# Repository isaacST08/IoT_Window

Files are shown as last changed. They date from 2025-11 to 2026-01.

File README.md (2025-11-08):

# IoT Window Project

This is a project creating an IoT (Internet of Things) window controller.

The project uses a Raspberry Pi Pico for the controller, a stepper motor, a
TMC2209 stepper motor driver, and a acme threaded rod for the physical movement
of the window, and 3D printed parts for mounting.

This device is designed to be used with Home assistant. On boot up of the
device, the device will send a HA device discovery packet that will
automatically configure the device in Home Assistant (when home assistant has
the MQTT integration set up to point to the same server you set up the IoT
window to connect to).

# Setup

Not included in the repo is the required `secrets.h` file that resides in the
`src` directory. To generate this file, use the command:

```
make secrets.h
```

If the file already exists, then nothing will happen, if it doesn't, then the
file will be created with all the required variables pre-filled with placeholder
values. Replace these values with the correct values for your network SSID and
password, as well as information for connecting to your MQTT server.

For manual creation of the `secrets.h` file, use the following template:

The file named `secrets.h` must be created in the `src` directory in order to
provide ones Wi-Fi credentials.

```
#ifndef SECRETS_H
#define SECRETS_H

#define WIFI_SSID "superCoolWiFiSSID"
#define WIFI_PASSWORD "superSecretPassword"

#define MQTT_SERVER "localhost"
#define MQTT_PORT 1883
#define MQTT_USER "mqtt"
#define MQTT_PASSWORD "mqttUserPassword"

#endif
```

Insert your Wi-Fi SSID and password in the appropriate locations.

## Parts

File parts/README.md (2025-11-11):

# Parts List

- 1x Raspberry Pi Pico W.
- 1x 42-40 Stepper Motor.
- 1x BigTreeTech TMC2209v1.3 Stepper Motor Driver.
- 2x Limit Switches (Mine are from a old Ender 3 V2 3D printer).
- 1x Acme threaded rod that is the slightly longer (or more) than the desired
  travel length of your window.
- 1x Matching acme threaded rod attachment nut.
- 1x Threaded rod to stepper motor coupler.
- 2x Threaded rod bearing mounts.
- 1x 30x10 standard bread board.
- 2x 150 ohm resistors.
- 1x 100 ohm resistor.
- 1x L7805CV voltage regulator.
- 1x Red LED.
- 1x Yellow LED.
- 1x Blue LED.
- 1x 100 microfarad, 30V+ capacitor.
- 1x Power supply, 12V to 28V (I'm using 12V).
- 1x Female barrel plug that matches power supply.
- 3x M4 * 20 Bolts.
- 3x M4 Nuts.
- 4x M3 * 8 Bolts.
- 4x M3 * 12 Bolts.
- 4x M3 * 20 Bolts.
- 4x M3 Nuts.
- Plenty of wires.
  - If only using a breadboard and following the breadboard wiring diagram, the
    low profile style breadboard wires will be needed.

# Tools

- A 3D printer or access to one that can print PETG.

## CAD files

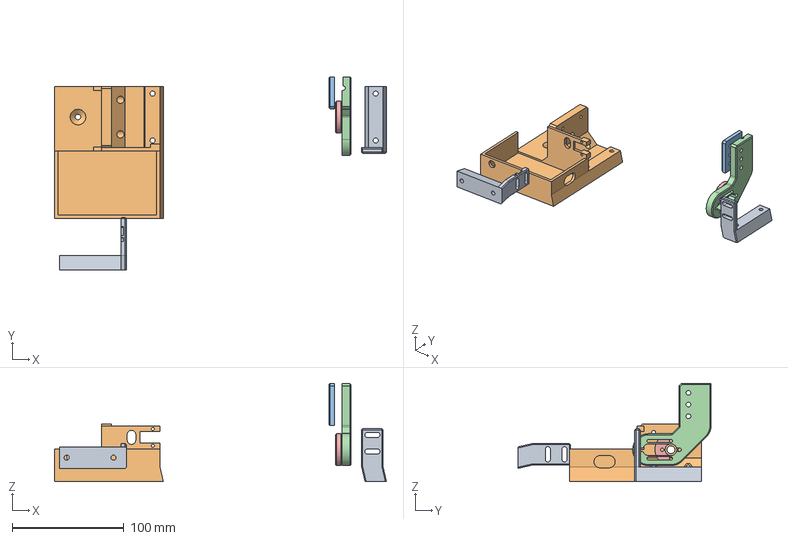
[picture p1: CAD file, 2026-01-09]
parts/cad/Mount_Mk2.FCStd
297.6 x 173.2 x 87.8 mm
Single_Block x 2
Motor_Mount
Window_Grab_Clamp
Window_Grab_Arm
Window_Grab_Arm_Clamp

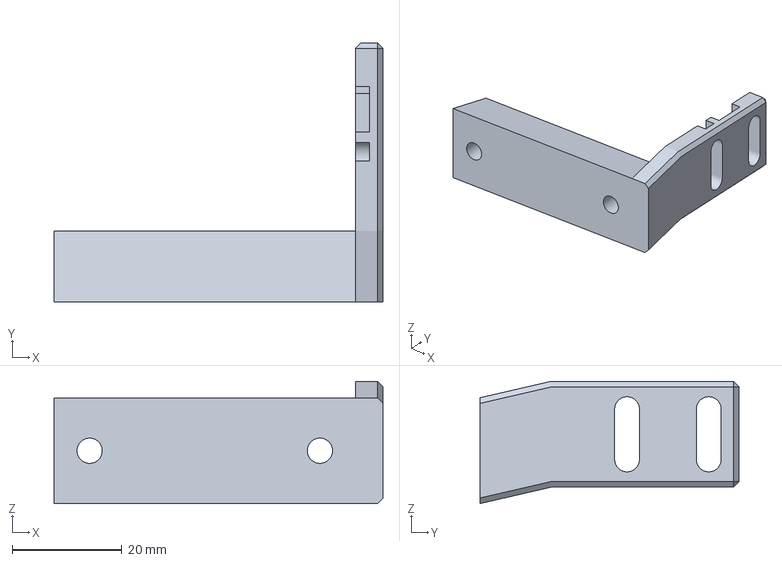
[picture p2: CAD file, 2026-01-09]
parts/cad/Mount_Mk2-Single_Block.3mf
60.0 x 47.3 x 22.3 mm

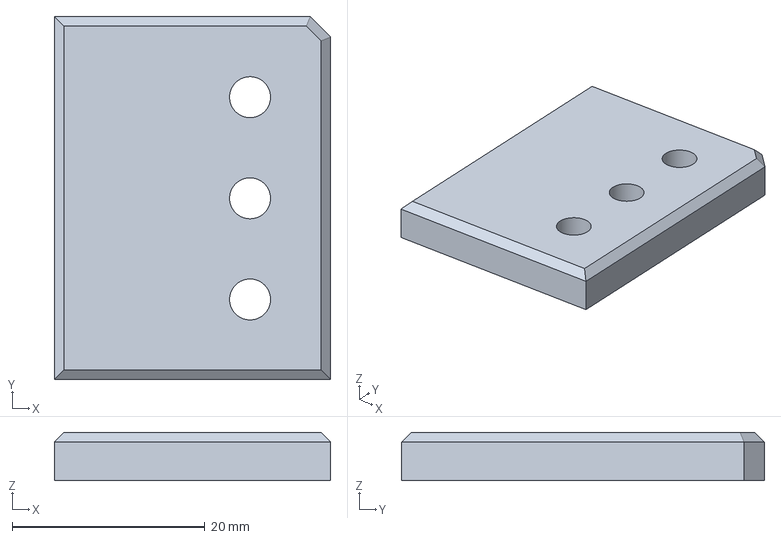
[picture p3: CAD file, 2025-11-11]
parts/cad/Mount_Mk2-Window_Grab_Clamp.3mf
28.7 x 37.7 x 5.00 mm

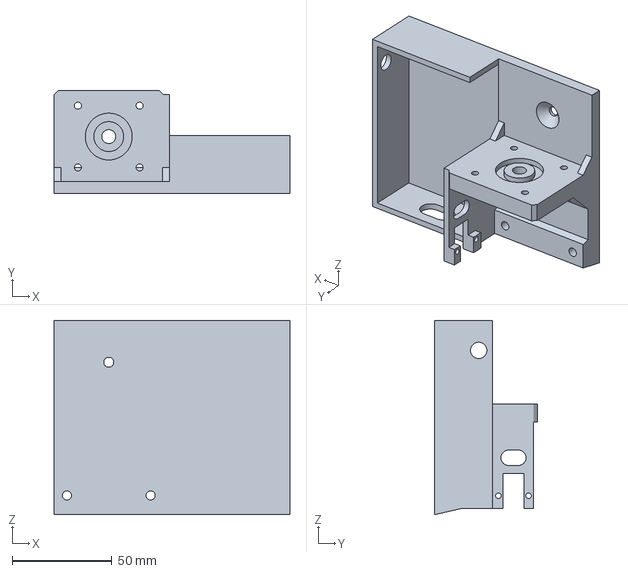
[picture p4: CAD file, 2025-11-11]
parts/cad/Mount_Mk2-Motor_Mount.3mf
118.5 x 51.5 x 97.6 mm

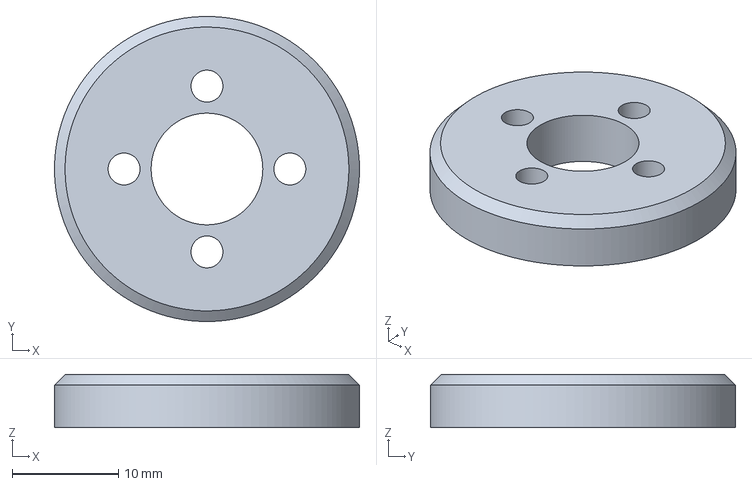
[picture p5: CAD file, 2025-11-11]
parts/cad/Mount_Mk2-Window_Grab_Arm_Clamp.3mf
28.7 x 28.7 x 5.00 mm

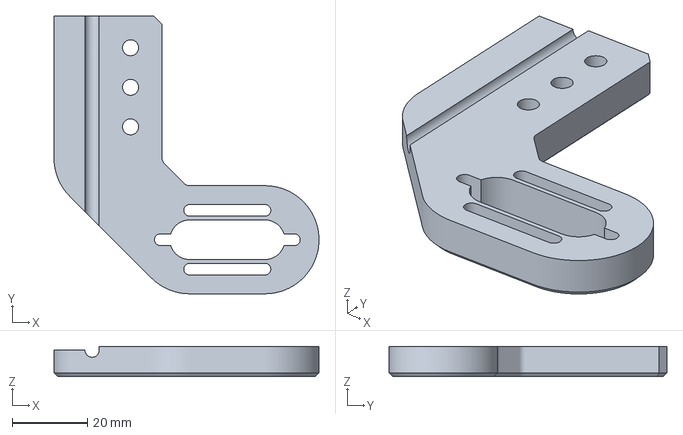
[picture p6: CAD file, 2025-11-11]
parts/cad/Mount_Mk2-Window_Grab_Arm.3mf
70.4 x 73.7 x 8.00 mm

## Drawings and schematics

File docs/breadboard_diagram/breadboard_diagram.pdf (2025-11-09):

+ - | + -

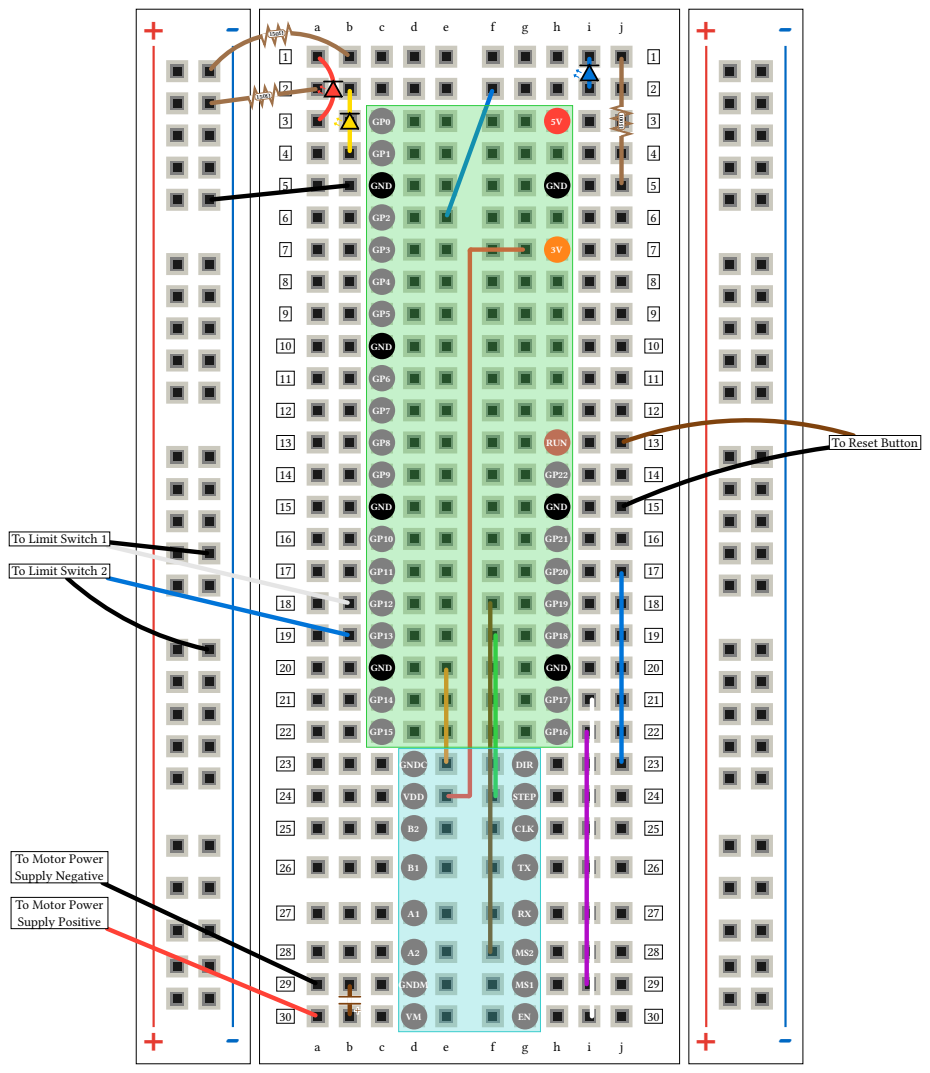
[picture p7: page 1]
GND; RUN; CLK; STEP; DIR; GNDM; VDD; GNDC

To Reset Button

To Limit Switch 1

To Limit Switch 2

To Motor Power
Supply Negative

Supply Positive

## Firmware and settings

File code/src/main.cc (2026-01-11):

#include <hardware/gpio.h>
#include <hardware/watchdog.h>
#include <pico/cyw43_arch.h>
#include <pico/stdio.h>

#include "ha_device.hh"
#include "network.hh"
#include "opts.hh"
#include "pins.hh"
#include "stepper_motor.hh"

/**
 * This is the main program start for the IoT window device.
 *
 * This will perform the tasks required to set up the device:
 * - Initialize IO.
 * - Initialize networking and MQTT.
 * - Initialize the device and hardware such as the stepper motor.
 * - Perform homing operations for the motor.
 *
 * Once setup is complete, the program goes into a main loop where
 * it performs repeated tasks such as checking the internet connection and
 * dispatching motor operations.
 */
int main() {
  /*
  **=========================================================================**
  ||                                                                         ||
  ||                ███████ ███████ ████████ ██    ██ ██████                 ||
  ||                ██      ██         ██    ██    ██ ██   ██                ||
  ||                ███████ █████      ██    ██    ██ ██████                 ||
  ||                     ██ ██         ██    ██    ██ ██                     ||
  ||                ███████ ███████    ██     ██████  ██                     ||
  ||                                                                         ||
  **=========================================================================**
  */

  // **=============================================**
  // ||          <<<<< GENERAL SETUP >>>>>          ||
  // **=============================================**

  // Initialize IO on the pico.
  stdio_init_all();
  sleep_ms(1000);

  // Once stdio has been initialized, announce the start of the program.
  printf("Program Start\n");
  stdio_flush();

  // Initialize the common pins (pins specific to a device get initialized with
  // that device).
  printf("Initializing Pins... ");
  init_pins();
  printf("done.\n");

  // Wave LEDs to visualize the start of the program without the need of a
  // console.
  {
    uint led_order[4] = {RED_LED_PIN, YELLOW_LED_PIN, BLUE_LED_PIN};
    int ms = 100;

    // Wave 3 times.
    for (int i = 0; i < 3; i++) {
      for (uint pin : led_order) {
        gpio_put(pin, 1);
        sleep_ms(ms);
      }
      for (uint pin : led_order) {
        gpio_put(pin, 0);
        sleep_ms(ms);
      }
    }
  }

  // **========================================**
  // ||          <<<<< WATCHDOG >>>>>          ||
  // **========================================**

  // Enable the yellow LED if the reboot was caused by the watchdog.
  if (watchdog_enable_caused_reboot()) gpio_put(YELLOW_LED_PIN, 1);

  printf("Enabling watchdog...");
  watchdog_enable(8388, 1);  // 8.388 seconds, max for RP2040.
  printf(" done.\n");

  // **=============================================**
  // ||          <<<<< NETWORK SETUP >>>>>          ||
  // **=============================================**

  // Initialize the network connection.
  printf("Initializing Networking... ");
  if (networkInit() != 0) {
    printf("Failed! Exiting.\n");
    stdio_flush();
    return -1;
  } else {
    printf("Success.\n");
  }

  // Print the memory size and the ring buffer size used by lwIP for debugging.
  if (MQTT_DEBUG)
    printf("MEMSIZE size: %d\nRINGBUF size: %d\n", MEM_SIZE,
           MQTT_OUTPUT_RINGBUF_SIZE);

  // ----- MQTT Setup -----
  printf("Setting up mqtt...\n");

  // Get lwIP locks while creating the MQTT client.
  cyw43_arch_lwip_begin();
  mqtt_client_t* mqtt_client = mqtt_client_new();
  cyw43_arch_lwip_end();

  // Attempt connection to the MQTT server and repeat until successful.
  printf("Insurring mqtt connection...\n");
  bool mqtt_setup_success;
  do {
    mqtt_setup_success = mqttDoConnect(mqtt_client);

    // Give MQTT subscribe requests that happen in the callback a chance to
    // complete.
    sleep_ms(1000);
  } while (!mqtt_setup_success);
  printf("MQTT setup finished.\n");

  // **============================================**
  // ||          <<<<< DEVICE SETUP >>>>>          ||
  // **============================================**

  // Initialize stepper motor for the window.
  stepper_motor::StepperMotor window_sm(SM_ENABLE_PIN, SM_DIR_PIN, SM_PULSE_PIN,
                                        SM_MS1_PIN, SM_MS2_PIN, MS_64,
                                        INITIAL_MOTOR_SPEED, mqtt_client);
  printf("Motor setup complete.\n");

  // Setup the Home Assistant device.
  haDeviceSetup(mqtt_client, &window_sm);

  // ----- WINDOW STEPPER MOTOR HOMING -----
  /*
   * Performs the homing operation for the window stepper motor.
   *
   * During the homing process the locks for lwIP and thus the network chip
   * itself are acquired. Even though control of the network chip is not
   * actively needed for this operation, the interrupts that occur due to the
   * network activity (specifically from the MQTT service) can cause problems
   * with the homing process. Problems range from stuttering during the motor
   * movement which can lead to an inaccurate reading of the home position and
   * unwanted noise, to the homing process getting interrupted and failing to
   * continue.
   *
   * Acquiring the locks simply makes the homing process smoother and more
   * reliable.
   *
   * Additionally, at prior to the motor being homed, any online device does not
   * know what state the window/motor is in and thus control of it via the
   * network isn't recommended anyways.
   *
   * For options related to the homing process such as the direction/side to
   * home to and which limit switch is on which side of the window, see the
   * `opts.h` file.
   */

  // Turn on the board led while the stepper motor is homing.
  cyw43_arch_gpio_put(CYW43_WL_GPIO_LED_PIN, 1);

  // Enable the motor (turn it on).
  window_sm.enable();

  // Perform the homing operation.
  printf("Homeing...\n");
  window_sm.home();
  printf("Homeing Complete.\n");

  // Disable the yellow LED that indicated this boot was caused by the watchdog
  // timing out.
  gpio_put(YELLOW_LED_PIN, 0);

  // Publish the current state of the device.
  window_sm.publishAll();

  /*
  **=========================================================================**
  ||                                                                         ||
  ||  ███    ███  █████  ██ ███    ██     ██       ██████   ██████  ██████   ||
  ||  ████  ████ ██   ██ ██ ████   ██     ██      ██    ██ ██    ██ ██   ██  ||
  ||  ██ ████ ██ ███████ ██ ██ ██  ██     ██      ██    ██ ██    ██ ██████   ||
  ||  ██  ██  ██ ██   ██ ██ ██  ██ ██     ██      ██    ██ ██    ██ ██       ||
  ||  ██      ██ ██   ██ ██ ██   ████     ███████  ██████   ██████  ██       ||
  ||                                                                         ||
  **=========================================================================**
  */

  unsigned int loop_iteration = 0;
  while (true) {
    // Feed watchdog on each loop.
    watchdog_update();

    // If the network connection is down, set the red LED on and attempt to
    // reconnect.
    if (cyw43_wifi_link_status(&cyw43_state, CYW43_ITF_STA) !=
        CYW43_LINK_JOIN) {
      gpio_put(RED_LED_PIN, 1);

      // Leave the network.
      wifiDisconnect();

      // Reconnect to the network.
      wifiConnect();

      gpio_put(RED_LED_PIN, 0);
    }

    // ----- PROCESS STEPPER MOTOR ACTIONS -----
    /*
     * Requested actions are set during network interrupts such as when an
     * appropriate MQTT packet is received.
     *
     * To allow for further network interrupts to occur during motor movement,
     * instead of processing the request during the interrupt, the interrupt
     * simply sets the flag for the action the motor should perform and then
     * returns control to the regular schedule. Then, during each round of the
     * main loop, the requested operation is performed here.
     *
     * While this design results in slightly delayed (and sometimes variable)
     * response times from when a MQTT command is sent from a different device
     * to when the action actually starts being performed, it allows for the
     * actually network interrupt to take far less time to complete and then
     * makes the device become available to more network interrupts before the
     * motor operation has concluded.
     *
     * This design allows for one command to come in, for example, to open the
     * window, and then to still accept more commands while the first command is
     * being completed. One such command that is very useful is the STOP
     * command. Without this design, once a command is being executed it must
     * complete, but with it, the user can send an MQTT command to open the
     * window, and then half way through (or in the even of an emergency) call
     * the command to stop the window. This allows for undecided movement
     * (non-percentage positioning) or for emergency stops (assuming networking
     * is still operational).
     *
     * The action queue allows multiple actions to be queued sequentially.
     * Actions are processed in FIFO order - first action queued is first
     * executed. The queue holds up to 8 actions by default.
     */

    if (window_sm.hasQueuedActions()) {
      using namespace stepper_motor::action;

      // Get the next action and its argument from the queue.
      Action action = window_sm.action_queue.dequeue();

      // Perform appropriate operation.
      switch (action.action_type) {
        // Open window.
        case ActionType::OPEN: {
          printf("Open window operation activated (queue size: %d)\n",
                 window_sm.action_queue.getCount());
          bool open_success = window_sm.open();
          break;
        }

        // Close window.
        case ActionType::CLOSE: {
          printf("Close window operation activated (queue size: %d)\n",
                 window_sm.action_queue.getCount());
          bool close_success = window_sm.close();
          break;
        }

        // Move to percentage position.
        case ActionType::MOVE_TO_PERCENT: {
          // Parse the percentage value.
          float percentage = CLAMP(0.0, action.data.percent, 100.0);

          printf("Move to %f%% operation activated (queue size: %d)\n",
                 percentage, window_sm.action_queue.getCount());

          // Move to the requested position.
          window_sm.moveToPositionPercentage(percentage);

          break;
        }

        // Move to step position.
        case ActionType::MOVE_TO_STEP: {
          // Parse the step value.
          uint64_t step = MAX(0, action.data.step);

          printf("Move to step %llu operation activated (queue size: %d)\n",
                 step, window_sm.action_queue.getCount());

          // Move to the requested position.
          window_sm.moveToPosition(step);

          break;
        }

        case ActionType::HOME: {
          window_sm.home();
          break;
        }

        case ActionType::CALIBRATE: {
          window_sm.calibrate();
          break;
        }

        // Do nothing.
        case ActionType::NONE:
          break;
      }
    }

    // Every ~20 minutes, publish all the stepper motor data to
    // insure the server stays in sync.
    if (loop_iteration % 1800 == 0) {
      window_sm.publishAll();
    }

    // Blink the board led through each main loop cycle.
    // This helps show whether the main loop is continuing or if the program
    // might be stuck somewhere.
    cyw43_arch_gpio_put(CYW43_WL_GPIO_LED_PIN, 1);
    sleep_ms(250);
    cyw43_arch_gpio_put(CYW43_WL_GPIO_LED_PIN, 0);
    sleep_ms(250);

    // Increment the loop iteration. It is fine if this wraps.
    loop_iteration += 1;
  }
}

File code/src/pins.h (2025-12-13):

#ifndef PINS_H
#define PINS_H

#include <hardware/gpio.h>
#include <pico/types.h>
#include <stdbool.h>

#define RED_LED_PIN 0
#define GREEN_LED_PIN 3  // Removed
#define YELLOW_LED_PIN 1
#define BLUE_LED_PIN 2

// Stepper Motor Pins
#define SM_ENABLE_PIN 17  // Stepper Motor Enable Pin
#define SM_DIR_PIN 20     // Stepper Motor Direction Pin
#define SM_PULSE_PIN 18   // Stepper Motor Pulse Pin
#define SM_MS1_PIN 16     // Stepper Motor Micro-Step Pin A
#define SM_MS2_PIN 19     // Stepper Motor Micro-Step Pin B

// Limit Switch Pins
#define LS_1 12  // Limit switch 1
#define LS_2 13  // Limit switch 2

// Micro-Step Configurations (Low bit for MS1, high bit for MS2).
#define MS_8 0b00
#define MS_16 0b11
#define MS_32 0b01
#define MS_64 0b10

#define MS_ENCODE(ms_int)   \
  ((ms_int == 8)    ? MS_8  \
   : (ms_int == 16) ? MS_16 \
   : (ms_int == 32) ? MS_32 \
   : (ms_int == 64) ? MS_64 \
                    : MS_64)

#define MS_DECODE(ms_pins)   \
  ((ms_pins == MS_8)    ? 8  \
   : (ms_pins == MS_16) ? 16 \
   : (ms_pins == MS_32) ? 32 \
   : (ms_pins == MS_64) ? 64 \
                        : 1)

void init_pins();
// void init_pin(uint pin, bool dir, bool init_val);

#endif

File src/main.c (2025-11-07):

#include <cyw43_country.h>
#include <cyw43_ll.h>
#include <hardware/gpio.h>
#include <lwip/apps/mqtt_opts.h>
#include <lwip/err.h>
#include <lwip/ip4_addr.h>
#include <lwip/ip_addr.h>
#include <pico/time.h>
#include <stdbool.h>
#include <stdio.h>
#include <string.h>

#include "advanced_opts.h"
#include "common.h"
#include "ha_device.h"
#include "limit_switch.h"
#include "lwip/apps/mqtt.h"
#include "network.h"
#include "pico/async_context.h"
#include "pico/cyw43_arch.h"
#include "pico/stdlib.h"
#include "pins.h"
#include "secrets.h"
#include "stepper_motor.h"

int main() {
  stdio_init_all();
  sleep_ms(1000);

  printf("Program Start\n");

  printf("Initializing Pins... ");
  init_pins();

  printf("done.\n");

  // Wave LEDs.
  for (int i = 0; i < 3; i++) {
    int ms = 100;
    gpio_put(RED_LED_PIN, 1);
    sleep_ms(ms);
    gpio_put(GREEN_LED_PIN, 1);
    sleep_ms(ms);
    gpio_put(YELLOW_LED_PIN, 1);
    sleep_ms(ms);
    gpio_put(BLUE_LED_PIN, 1);
    sleep_ms(ms);
    gpio_put(RED_LED_PIN, 0);
    sleep_ms(ms);
    gpio_put(GREEN_LED_PIN, 0);
    sleep_ms(ms);
    gpio_put(YELLOW_LED_PIN, 0);
    sleep_ms(ms);
    gpio_put(BLUE_LED_PIN, 0);
    sleep_ms(ms);
  }

  // Initialize the network connection.
  printf("Initializing Networking...");
  if (network_init() != 0) {
    // printf("Failed to initialize network connection.\n");
    printf("Failed! Exiting.\n");
    return -1;
  } else {
    printf("Success.\n");
    // printf("Network setup successful.\n");
  }

  printf("MEMSIZE size: %d\n", MEM_SIZE);
  printf("RINGBUF size: %d\n", MQTT_OUTPUT_RINGBUF_SIZE);

  // enum DeviceState *queued_motor_move;
  // *queued_motor_move = STOPPED;
  // enum DeviceState queued_motor_move = STOPPED;
  // uint64_t motor_speed = 40;

  // sm_set_speed_ptr(&motor_speed);

  // for (int i = 0; i < 15; i++) {
  //   gpio_put(RED_LED_PIN, 1);
  //   gpio_put(GREEN_LED_PIN, 1);
  //   sleep_ms(300);
  //   gpio_put(RED_LED_PIN, 0);
  //   gpio_put(GREEN_LED_PIN, 0);
  //   sleep_ms(300);
  // }

  // Initialize Stepper Motor.
  StepperMotor stepper_motor;
  smInit(&stepper_motor, SM_ENABLE_PIN, SM_DIR_PIN, SM_PULSE_PIN, SM_MS1_PIN,
         SM_MS2_PIN, MS_64, 1);

  // MQTT Setup
  printf("Setting up mqtt...\n");
  cyw43_arch_lwip_begin();
  mqtt_client_t *mqtt_client = mqtt_client_new();
  cyw43_arch_lwip_end();
  printf("Insurring mqtt connection...\n");
  bool mqtt_setup_success;
  do {
    mqtt_setup_success = mqttDoConnect(mqtt_client);
  } while (!mqtt_setup_success);
  printf("MQTT setup finished\n");

  // printf("Setting up mqtt...\n");
  // cyw43_arch_lwip_begin();
  // mqtt_client_t *mqtt_client = mqtt_client_new();
  // if (mqtt_client != NULL) {
  //   mqtt_do_connect(mqtt_client);
  // } else {
  //   for (int i = 0; i < 15; i++) {
  //     gpio_put(RED_LED_PIN, 1);
  //     gpio_put(GREEN_LED_PIN, 1);
  //     sleep_ms(300);
  //     gpio_put(RED_LED_PIN, 0);
  //     gpio_put(GREEN_LED_PIN, 0);
  //     sleep_ms(300);
  //   }
  // }
  // printf("MQTT setup finished\n");
  // cyw43_arch_lwip_end();

  haDeviceSetup(mqtt_client, &stepper_motor);
  // bool ha_dev_discovery_msg_sent;
  // do {
  //   ha_dev_discovery_msg_sent = haDeviceSetup(mqtt_client, &stepper_motor);
  // } while (!ha_dev_discovery_msg_sent);

  // mqtt_publish_device_config(mqtt_client, NULL);
  // example_publish(mqtt_client, NULL);
  // cyw43_arch_lwip_end();

  // Turn on the board led.
  cyw43_arch_gpio_put(CYW43_WL_GPIO_LED_PIN, 1);

  cyw43_arch_lwip_begin();
  smEnable(&stepper_motor);
  printf("Homeing...\n");
  smHome(&stepper_motor);
  printf("Homeing Complete.\n");
  cyw43_arch_lwip_end();

  while (true) {
    gpio_put(RED_LED_PIN, cyw43_wifi_link_status(&cyw43_state, CYW43_ITF_STA) !=
                              CYW43_LINK_JOIN);

    if (stepper_motor.queued_action != SM_ACTION_NONE) {
      printf("Queued motor move: %d\n", stepper_motor.queued_action);
      switch (stepper_motor.queued_action) {
        case SM_ACTION_OPEN: {
          printf("Open motor activated\n");
          bool open_success = smOpen(&stepper_motor);
          // if (open_success) {
          //   // basicMqttPublish(MQTT_TOPIC_STATE_GENERAL, "open", 1, 0);
          //   // updateState(OPEN);
          // } else {
          //   printf("Stopping motor\n");
          //   updateState(STOPPED);
          // }
          // queued_motor_move = STOPPED;
          break;
        }
        case SM_ACTION_CLOSE: {
          bool close_success = smClose(&stepper_motor);
          // if (close_success) {
          //   // basicMqttPublish(MQTT_TOPIC_STATE_GENERAL, "close", 1, 0);
          //   updateState(CLOSED);
          // } else {
          //   updateState(STOPPED);
          // }
          // queued_motor_move = STOPPED;
          break;
        }
        case SM_ACTION_NONE:
          break;
          // default:
          //   // queued_motor_move = STOPPED;
          //   break;
      }
      // queued_motor_move = STOPPED;
      publishAll();
    }

    cyw43_arch_gpio_put(CYW43_WL_GPIO_LED_PIN, 1);
    sleep_ms(250);
    cyw43_arch_gpio_put(CYW43_WL_GPIO_LED_PIN, 0);
    sleep_ms(250);
  }
}

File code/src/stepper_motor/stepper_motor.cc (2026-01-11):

#include "stepper_motor.hh"

#include <hardware/watchdog.h>
#include <math.h>
#include <pico/cyw43_arch.h>
#include <pico/platform/compiler.h>

#include "action_queue.hh"
#include "advanced_opts.hh"
#include "common.hh"
#include "limit_switch.hh"
#include "mqtt_topics.hh"
#include "pins.hh"

using namespace stepper_motor;

#define MM_PER_SEC_TO_US_PER_HALF_MICROSTEP(mm_per_sec, micro_step) \
  (round(1000000.0 / (mm_per_sec * SM_FULL_STEPS_PER_MM * micro_step * 2)))

#define US_PER_HALF_MICROSTEP_TO_MM_PER_SEC(us_per_half_ms, micro_step) \
  (1000000.0 / (us_per_half_ms * SM_FULL_STEPS_PER_MM * micro_step * 2))

#define INIT_PIN(pin, dir, val) \
  gpio_init(pin);               \
  gpio_set_dir(pin, dir);       \
  if (dir == GPIO_OUT) gpio_put(pin, val)

//
//
// **===========================================**
// ||          <<<<< CONSTRUCTOR >>>>>          ||
// **===========================================**

/**
 * Initialize a stepper motor object.
 *
 * \param enable_pin The enable pin of the motor.
 * \param direction_pin The direction pin of the motor.
 * \param pulse_pin The pulse/step pin of the motor.
 * \param micro_step_1_pin The first of the two micro step encoding pins for the
 * motor.
 * \param micro_step_2_pin The second of the two micro step encoding pins for
 * the motor.
 * \param initial_micro_step The initial micros step to set the motor to.
 * \param initial_speed The initial speed to set the motor to.
 */
stepper_motor::StepperMotor::StepperMotor(uint enable_pin, uint direction_pin,
                                          uint pulse_pin, uint micro_step_1_pin,
                                          uint micro_step_2_pin,
                                          uint initial_micro_step,
                                          float initial_speed,
                                          mqtt_client_t* mqtt_client) {
  // Set stepper motor pins.
  this->pins.enable = enable_pin;
  this->pins.direction = direction_pin;
  this->pins.pulse = pulse_pin;
  this->pins.ms1 = micro_step_1_pin;
  this->pins.ms2 = micro_step_2_pin;

  // ----- Initialize the pins -----
  // Enable Pin.
  INIT_PIN(this->pins.enable, GPIO_OUT, 0);

  // Motor Direction Pin.
  INIT_PIN(this->pins.direction, GPIO_OUT, 0);

  // Motor Pulse Pin.
  INIT_PIN(this->pins.pulse, GPIO_OUT, 0);

  // Stepper Motor Micro-Step Pin A.
  INIT_PIN(this->pins.ms1, GPIO_OUT, 0);

  // Stepper Motor Micro-Step Pin B.
  INIT_PIN(this->pins.ms2, GPIO_OUT, 0);

  // ----- Set Initial Values -----

  // Set the default window width.
  this->window_open_step_position = DEFAULT_WINDOW_OPEN_STEP_POSITION;

  // Don't publish updates until the MQTT client is fully setup.
  this->publish_updates = false;

  // Quiet mode off by default.
  this->quiet_mode = false;

  // Soft start mode on by default.
  this->soft_start_mode = true;

  // Temporary flag to ignore main soft start flag when performing two
  // actions of the same type in the same direction.
  this->roll_soft_start = false;

  // No call to stop the motor.
  this->stop_motor = false;

  // Zero the position (assume).
  this->step_position = 0;

  // Initialize the action queue.
  this->action_queue = action::ActionQueue();

  // Not moving.
  this->state = State::STOPPED;

  // Set the initial micro steps value of the motor.
  this->setMicroStep(initial_micro_step);

  // Default motor speed.
  this->setSpeed(initial_speed);

  // Set the MQTT client.
  this->mqtt_client = mqtt_client;
}

//
//
// **=====================================**
// ||          <<<<< BASIC >>>>>          ||
// **=====================================**

/**
 * Enables the stepper motor.
 */
void StepperMotor::enable() { gpio_put(this->pins.enable, 0); }

/**
 * Disables the stepper motor.
 */
void StepperMotor::disable() { gpio_put(this->pins.enable, 1); }

//
//
// **=========================================**
// ||          <<<<< DIRECTION >>>>>          ||
// **=========================================**

/**
 * Gets the current direction of the stepper motor.
 *
 * \returns The current direction of the motor.
 *          0 is clockwise, 1 is counter clockwise.
 */
direction_t StepperMotor::getDir() { return gpio_get(this->pins.direction); }

/**
 * Set the direction of the stepper motor.
 *
 * \param dir The direction to set.
 *            0 is clockwise, 1 is counter clockwise.
 */
void StepperMotor::setDir(direction_t dir) {
  gpio_put(this->pins.direction, dir);
}

/**
 * Swaps the current direction of the stepper motor.
 */
void StepperMotor::swapDir() { this->setDir(this->getDir() ^ 1); }

//
//
// **==========================================**
// ||          <<<<< QUIET MODE >>>>>          ||
// **==========================================**

/**
 * Gets the current quiet mode of the motor.
 */
bool StepperMotor::getQuietMode() { return this->quiet_mode; }

/**
 * Sets the quiet mode for the motor.
 *
 * \param mode Whether to enable or disable quiet mode.
 */
void StepperMotor::setQuietMode(bool mode) {
  // Set the quiet mode flag.
  this->quiet_mode = mode;

  // Update the motor speed.
  this->setSpeed(this->speed);

  // Relay the change in quiet mode to the MQTT server.
  this->publishQuietMode();
}

//
//
// **===============================================**
// ||          <<<<< SOFT START MODE >>>>>          ||
// **===============================================**

/**
 * Gets the current soft start mode of the motor.
 */
bool StepperMotor::getSoftStartMode() { return this->soft_start_mode; }

/**
 * Sets the soft start mode for the motor.
 *
 * \param mode Whether to enable or disable soft start mode.
 */
void StepperMotor::setSoftStartMode(bool mode) {
  // Set the soft start mode flag.
  this->soft_start_mode = mode;
  this->roll_soft_start = false;

  // Relay the change in soft start mode to the MQTT server.
  this->publishSoftStartMode();
}

//
//
// **===========================================**
// ||          <<<<< MICRO STEPS >>>>>          ||
// **===========================================**

/**
 * Returns the current micro-step pin encoded state.
 *
 * Compare against one of MS_8, MS_16, MS_32, MS_64 for a human readable value.
 *
 * \returns The current micro-step state in it's binary pin form.
 */
uint StepperMotor::getMicroStep() {
  return (((uint)gpio_get(this->pins.ms2) << 1) |
          (uint)gpio_get(this->pins.ms1));
}

/**
 * Returns the current micro-steps of the motor as an int.
 *
 * \returns The current micro-step state in it's integer form.
 */
uint StepperMotor::getMicroStepInt() {
  return (MS_DECODE(this->getMicroStep()));
}
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

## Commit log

2025-10-13 Rudamentary stepper motor driver
2025-10-14 Working towards getting mqtt working
    Small packets work, large packets cause a crash
    [ha_device.h, main.c, network.c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]
2025-10-19 Working HA MQTT device discovery message
2025-10-27 Added pins for limit switches
2025-10-27 Added set direction and homing functions for the stepper motor.
2025-10-27 Added homing to main script
2025-10-30 Overhauled stepper motor implementation
2025-10-31 Created limit switch class
2025-10-31 Removed initialization of stepper motor pins now handled inside smInit
2025-10-31 Simplified limit switch library
2025-10-31 Added error messages to newtowk connecting process
    [network.c]
2025-10-31 Added more error messaging
    [network.c]
2025-10-31 Incremental changes and bug fixes
    [stepper_motor.c]
2025-10-31 Fixed direction tracking bug
    [ha_device.c, stepper_motor.c]
2025-11-07 Changed stepper motor speed to be a value of millimeters per second
2025-11-07 Migrated stepper motor lib into C++
2025-11-07 Converted files to C++, implemented new C++ version of stepper_motor, and updated CMakeLists accordingly
2025-11-08 Fixed device not subscribing to MQTT topics bug
    [ha_device.cc, main.cc]
2025-11-09 Updated pins to match the new wiring diagram
2025-11-11 Added stepper motor driver datasheet
2025-11-11 Added custom parts
    [Mount_Mk2-Motor_Mount.3mf, Mount_Mk2-Single_Block.3mf, Mount_Mk2-Window_Grab_Arm.3mf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]
2025-12-12 Added more functions to stepper motor
2025-12-13 Added function to initialize a single pin
2025-12-13 Migrated MQTT publish code directly into stepper motor
2025-12-16 Added options for the speed of homing and small bug fixes
    [advanced_opts.h]
2025-12-16 Made the order of CLAMP arguments more intuitive
2025-12-16 Small bug fixes and improvements
    [ha_device.cc]
2025-12-16 Bugfixes and updated labels
    [main.cc]
2025-12-17 Add full FIFO action queue for stepper motor
    Replace single-element action queue with a proper FIFO circular buffer
    that can hold up to 8 motor actions. This allows multiple commands to
    be queued sequentially rather than being overwritten.
    Changes:
    - Add action_queue.hh with macro-based queue implementation
    - Add enqueue/dequeue/peek/hasQueuedActions/clearQueue methods
    - Update main loop to dequeue actions sequentially
    - stop() now clears entire queue for emergency stops
    - Legacy queueAction() now enqueues instead of overwriting
    [main.cc, stepper_motor.cc]
2025-12-19 closes #6; Fixed problem where the real speed of the motor was not being reported to HA
    [ha_device.cc, stepper_motor.cc]
2026-01-09 Updated single block to have mounting place for limit switch.
    [Mount_Mk2-Single_Block.3mf, Mount_Mk2.FCStd]
2026-01-09 Added function for calibrating the window in either direction.
2026-01-10 Moved stepper motor related files into a subdir
2026-01-10 Added home and calibrate buttons to HA and added default entity icons.
2026-01-10 Fixed bug in steps conversion function not referencing steps arg
    [stepper_motor.cc]
2026-01-10 Added variable window width that is set by calibration.
2026-01-10 Changed main loop to publish the state of the device every 20 minutes
2026-01-11 Implemented motor soft start toggle in home assistant
